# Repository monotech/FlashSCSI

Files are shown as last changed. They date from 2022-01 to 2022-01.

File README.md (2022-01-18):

Intended for classic Macs starting with the Macintosh Plus, this is a Super-miniature clone of the SCSI2SD v4.2b by Michael McMaster.

Original SCSI2SD source files here: http://www.codesrc.com/gitweb/index.cgi?p=SCSI2SD.git;a=tree

If the semiconductor shortage hasn't caused them to dry up, I should have assembled stock for sale at http://monotech.fwscart.com

Mechanical parts required for assembly of the enclosure panels:
2 x screws: 2-56 UNC, 5/32" long
2 x nuts: 2-56 UNC
4 x M-F hex spacers: 3/16" body length, 5/32" screw length, 2-56 UNC thread. Example part: Fascomp FC4500-256-A

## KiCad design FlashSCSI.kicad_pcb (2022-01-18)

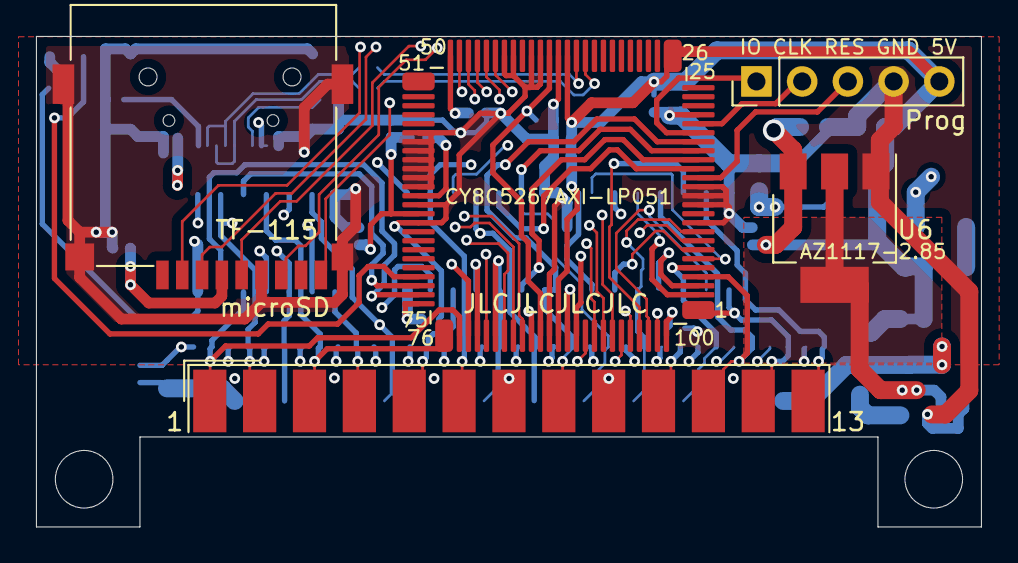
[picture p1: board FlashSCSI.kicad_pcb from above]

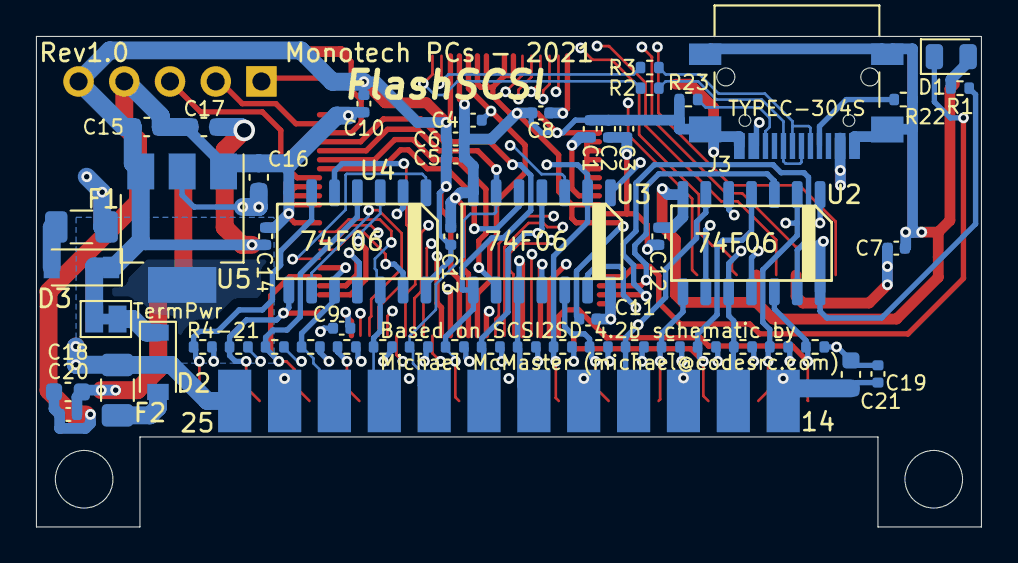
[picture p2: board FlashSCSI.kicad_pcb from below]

Board: 4 copper layers, 52.5 x 27.2 mm, 60 parts (55 on the bottom side), 63 nets.

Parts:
C1, C2, C4, C5: 1uF; C_0402_1005Metric
C3, C6, C7, C8, C9, C10, C11, C12, C13, C14, C19, C20: 100nF; C_0402_1005Metric
C15, C16, C17, C18, C21: 10uF; C_0603_1608Metric
D1: Activity; LED_0805_2012Metric
D2, D3: B5819W; D_SOD-123
F1, F2: 1A; Fuse_1206_3216Metric
J1: Prog; PinHeader_1x05_P2.54mm_Vertical
J2: microSD; microSD_HC_XunPu_TF-115
J3: USB; USB_C_Receptacle_XunPu_TYPEC-304S
J4: SCSI; DSUB-25_Male_EdgeMount_P2.77mm
JP1: TermPwr; SolderJumper-2_P1.3mm_Bridged_Pad1.0x1.5mm
R1: 2.2k; R_0402_1005Metric
R2, R3: 22; R_0402_1005Metric
R4, R5, R6, R7, R8, R9, R10, R11, R12, R13, R14, R15, R16, R17, R18, R19, R20, R21: 110; R_0402_1005Metric
R22, R23: 5.6k; R_0402_1005Metric
U1: CY8C5267AXI-LP051; LQFP-100_14x14mm_P0.5mm
U2, U3, U4: 74F06; SOIC-14_3.9x8.7mm_P1.27mm
U5: AZ1117-3.3; SOT-223-3_TabPin2
U6: AZ1117-2.85; SOT-223-3_TabPin2

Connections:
+3V3: C7.1, C8.1, C16.1, J2.4, U1.50, U5.2
+5V: C2.1, C3.1, C5.1, C6.1, C9.1, C10.1, C11.1, C12.1, C13.1, C14.1, C15.1, C17.1, D3.1, J1.5, JP1.2, R1.1, U1.26, U1.37, U1.65, U1.75, U1.88, U1.100, U2.14, U3.14, U4.14, U5.3, U6.3
/ACK: U1.89, U3.13
/ATN: U1.93, U2.5
/BSY: U1.90, U3.1
/CD: U1.78, U2.11
/C_USBD+: J3.A6, J3.B6, R2.2
/C_USBD-: J3.A7, J3.B7, R3.2
/DB0: U1.17, U3.9
/DB1: U1.16, U3.5
/DB2: U1.7, U4.13
/DB3: U1.6, U4.1
/DB4: U1.3, U4.11
/DB5: U1.2, U4.3
/DB6: U1.98, U4.9
/DB7: U1.97, U4.5
/DBP: U1.94, U3.3
/IO: U1.73, U2.3
/MSG: U1.82, U2.1
/REQ: U1.74, U2.13
/RST: U1.83, U2.9
/SD_MISO: J2.7, U1.45
/SD_MOSI: J2.3, U1.47
/SD_SCK: J2.5, U1.46
/SEL: U1.79, U3.11
/SWDCLK: J1.2, U1.21
/SWDIO: J1.1, U1.20
/Term_Pwr: F2.2, J4.25
/USBD+: R2.1, U1.35
/USBD-: R3.1, U1.36
/~ACK: J4.5, R19.1, U1.91, U3.12
/~ATN: J4.17, R21.1, U1.95, U2.6
/~BSY: J4.6, R20.1, U1.92, U3.2
/~CD: J4.15, R15.1, U1.80, U2.10
/~DB0: J4.8, R12.1, U1.19, U3.8
/~DB1: J4.21, R11.1, U1.18, U3.6
/~DB2: J4.22, R10.1, U1.9, U4.12
/~DB3: J4.10, R9.1, U1.8, U4.2
/~DB4: J4.23, R8.1, U1.5, U4.10
/~DB5: J4.11, R7.1, U1.4, U4.4
/~DB6: J4.12, R6.1, U1.1, U4.8
/~DB7: J4.13, R5.1, U1.99, U4.6
/~DBP: J4.20, R4.1, U1.96, U3.4
/~IO: J4.3, R13.1, U1.76, U2.4
/~MSG: J4.2, R17.1, U1.84, U2.2
/~REQ: J4.1, R14.1, U1.77, U2.12
/~RST: J4.4, R18.1, U1.85, U2.8
/~SD_CD: J2.9, U1.49
/~SD_CS: J2.2, U1.48
/~SEL: J4.19, R16.1, U1.81, U3.10
/~XRES: J1.3, U1.15
GND: C1.2, C2.2, C3.2, C4.2, C5.2, C6.2, C7.2, C8.2, C9.2, C10.2, C11.2, C12.2, C13.2, C14.2, C15.2, C16.2, C17.2, C18.2, C19.2, C20.2, C21.2, J1.4, J2.6, J2.10, J3.A1, J3.A12, J3.B1, J3.B12, J3.S1, J4.7, J4.9, J4.14, J4.16, J4.18, J4.24, R22.1, R23.1, U1.10, U1.12, U1.13, U1.14, U1.22, U1.38, U1.40, U1.41, U1.43, U1.44, U1.56, U1.57, U1.58, U1.59, U1.60, U1.61, U1.62, U1.64, U1.66, U1.87, U2.7, U3.7, U4.7, U5.1, U6.1
unnamed: C1.1, U1.63
unnamed: C4.1, U1.39, U1.86
unnamed: C18.1, C19.1, C20.1, C21.1, R4.2, R5.2, R6.2, R7.2, R8.2, R9.2, R10.2, R11.2, R12.2, R13.2, R14.2, R15.2, R16.2, R17.2, R18.2, R19.2, R20.2, R21.2, U6.2
unnamed: D1.1, U1.72
unnamed: D1.2, R1.2
unnamed: D2.1, JP1.1
unnamed: D2.2, F2.1
unnamed: D3.2, F1.1
unnamed: F1.2, J3.A4, J3.A9, J3.B4, J3.B9
unnamed: J3.A5, R22.2
unnamed: J3.B5, R23.2
